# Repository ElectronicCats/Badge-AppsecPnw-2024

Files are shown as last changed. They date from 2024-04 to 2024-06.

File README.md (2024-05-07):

# Badge pnwCON 2024

## Getting started

1. Connect Badge via USB to your computer.
2. Open the serial port indicated for the badge on your computer through a program such as Arduino IDE, Putty or Screen at 115200 bauds.
3. The badge text should appear in the terminal.

## Tecnologia

- ESP32C6
- LEDs
- USB

## Gratitude
Do you want to say thank you? Tag these companies on social networks and show them your badge, thanks to them it is possible

- [WebSEC](https://www.websec.ca)
- [ElectronicCats](https://electroniccats.com/)

## License

Electronic Cats invests time and resources providing this open source design, please support Electronic Cats and open-source hardware by purchasing products from Electronic Cats!

Designed by Electronic Cats.

Hardware released under an CERN Open Hardware Licence v1.2. See the LICENSE_HARDWARE file for more information.

Electronic Cats is a registered trademark, please do not use if you sell these PCBs.

May 2024

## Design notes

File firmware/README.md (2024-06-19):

# AppsecPwn
Application in the firmware:
- Wifi
  - Deauth:
  - Broadcast: Send broadcast packets to the selected AP.
  - Rogue AP: Clone the selected AP.
  - Combine: Create a clone of the selected AP and send broadcast packets to the real AP.
  - Multi-AP: Create APs for all the scanned networks.
  - Captive portal:
    - Google: Request credentials from the user.
    - WIFI Pass: Steal the WiFi password by asking the user to enter their network password.
- BLE
  - Trackers: Scanner for Airtags and Tile devices.
  - Spam: Send ADV packets to connect devices to an Apple device.
  - Game: Game based on OWASP vulnerabilities.
- Zigbee
  - Sniffer: IEEE 802.15.4 Sniffer, requires a computer serial connection.
- Settings
  - Display: Change the logo screen. If the bonus logos are unlocked, this option allows you to change the logo.

## Game
When entering pairing mode, the game must have a Blue team player and a Red team player. The devices need to be close to each other to start the game. Once started, the Red team player selects the OWASP profile to use and then the attack. When the attack is sent, the Blue team player receives it and must select a mitigation measure. If the mitigation is successful, the Blue team wins the round and the Red team loses points. The game ends when either team loses all their points.

### Unlocks
To unlock the logos, the player must win 10 games using the 10 OWASP profiles. Every 3 profiles unlock a new level until the highest level is reached.
Levels:
Jedi:
Level 1: Padawan
Level 2: Knight
Level 3: Master
Level 4: Grand Master <- Highest Level
Sith:
Level 1: Lord
Level 2: Master
Level 3: Darth
Level 4: Dark Lord <- Highest level

It is not required to unlock the backgrounds in a specific order; the condition is to win games with different profiles. To unlock faster, it is convenient to win each game using different attacks. Each game saves which profile was used; if you win with those profiles, an internal flag is set which allows you to level up.

### Profile map

#### Part 1
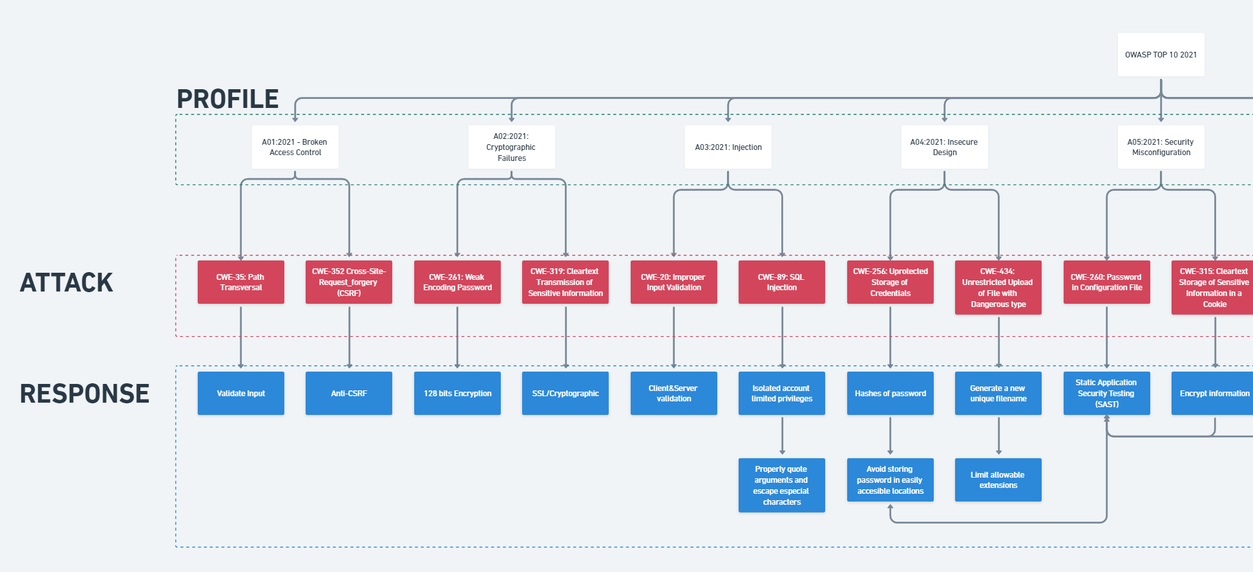
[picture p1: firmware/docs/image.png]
Part 1 - Profile map

#### Part 2
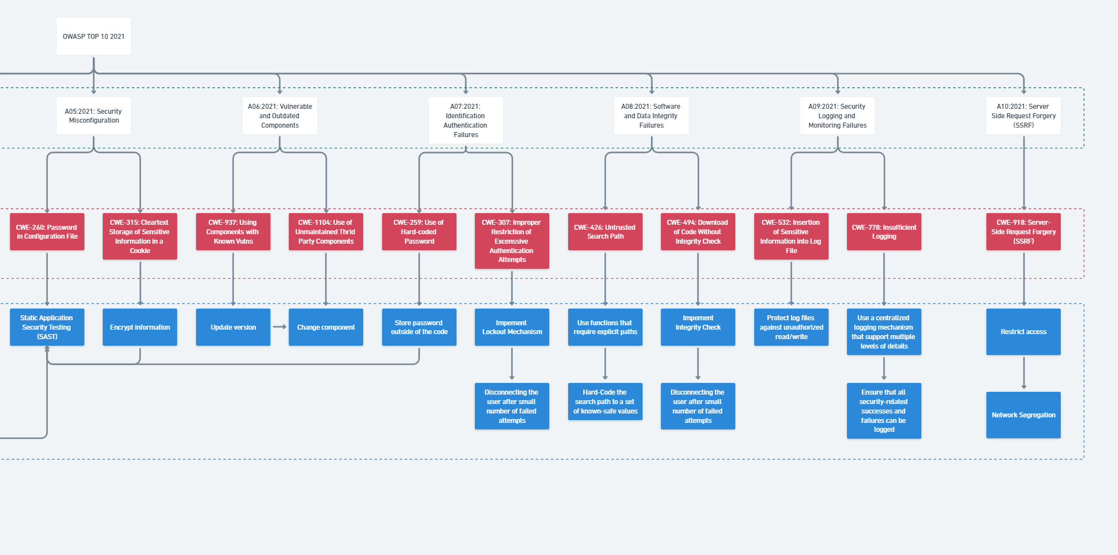
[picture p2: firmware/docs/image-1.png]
Part 2 - Profile map


### Logos
#### Sith Logo
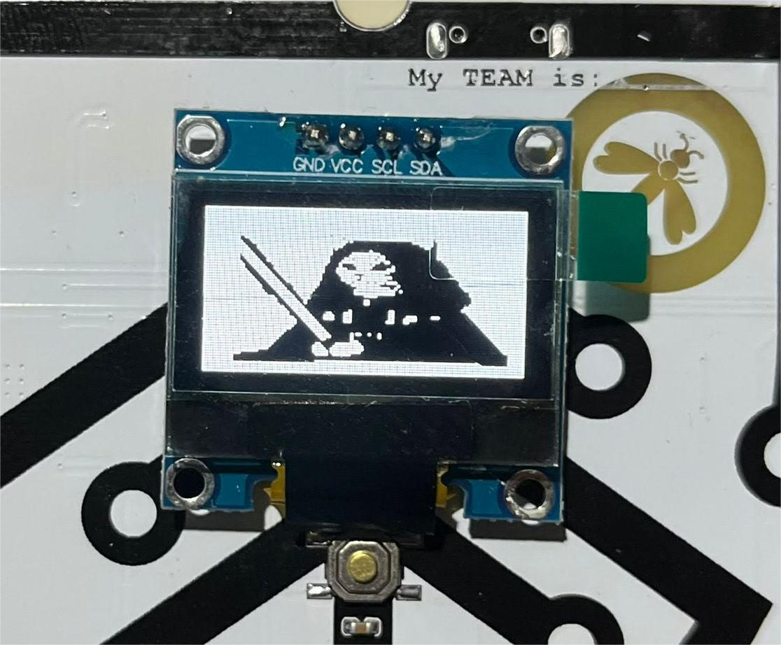
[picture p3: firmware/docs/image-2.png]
Sith logo

#### Jedi Logo
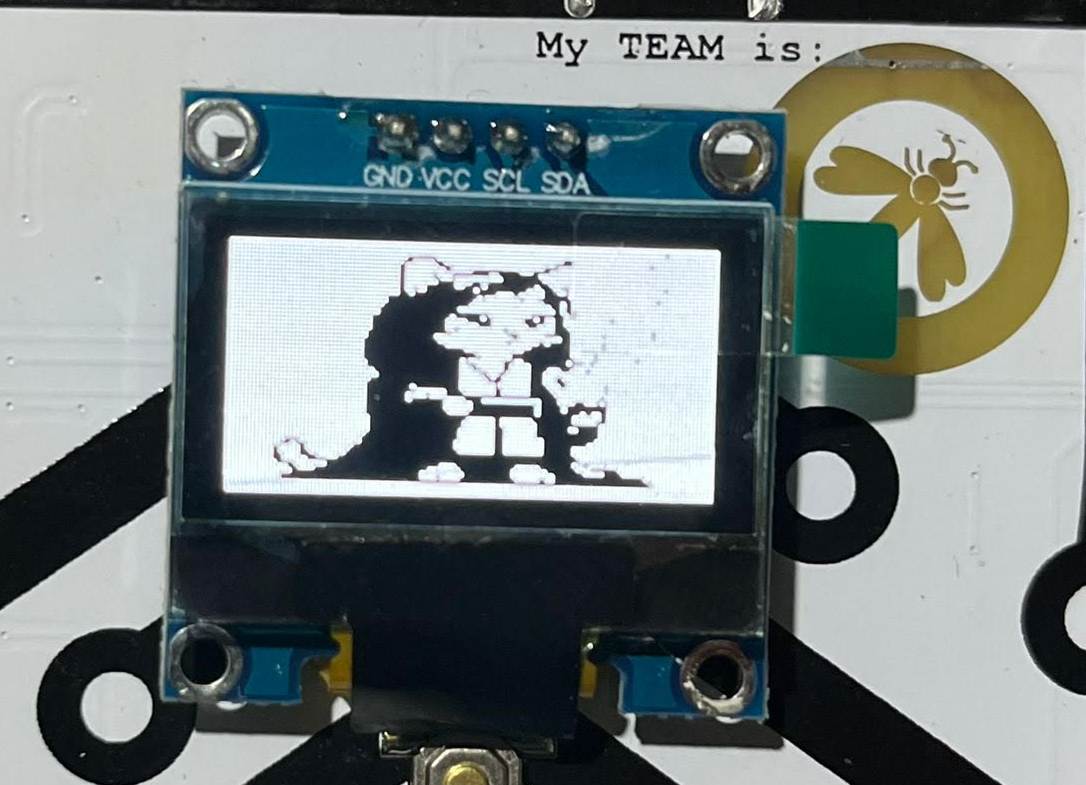
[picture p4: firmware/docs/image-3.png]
Jedi log


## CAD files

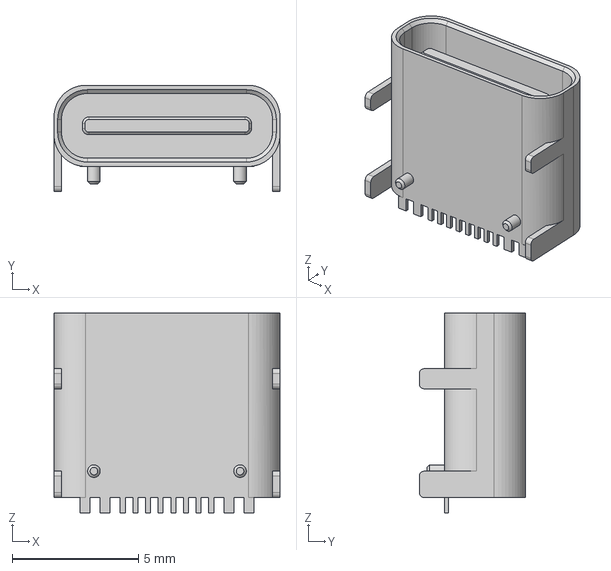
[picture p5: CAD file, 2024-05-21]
hardware/Footprints/3D/HRO TYPE-C-31-M-12.step
8.94 x 4.21 x 7.90 mm

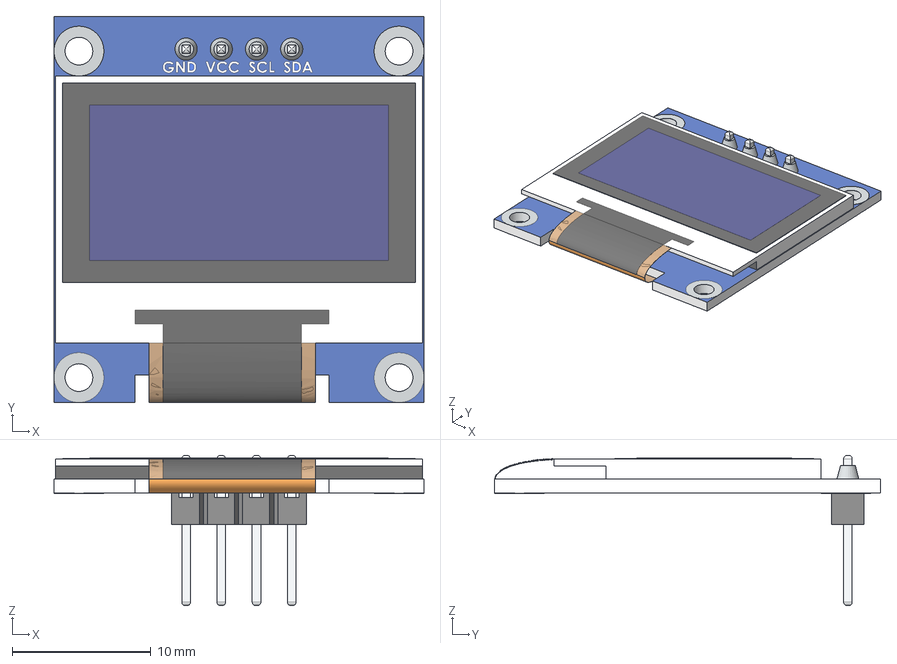
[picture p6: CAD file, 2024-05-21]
hardware/Footprints/3D/OLED-128x64-0.96.step
26.7 x 27.9 x 10.8 mm

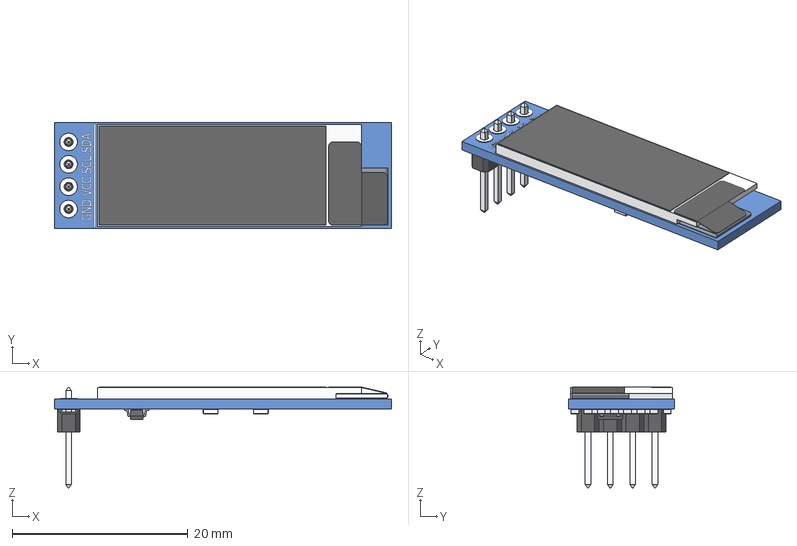
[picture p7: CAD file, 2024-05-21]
hardware/Footprints/3D/OLED_0.91_128x32.stp
38.3 x 12.1 x 11.5 mm
OLED_0.91_128x32
Pin Header 4 x 1 TH 2.54mm Pitch
RESC-0603 x 13
2SD0601A

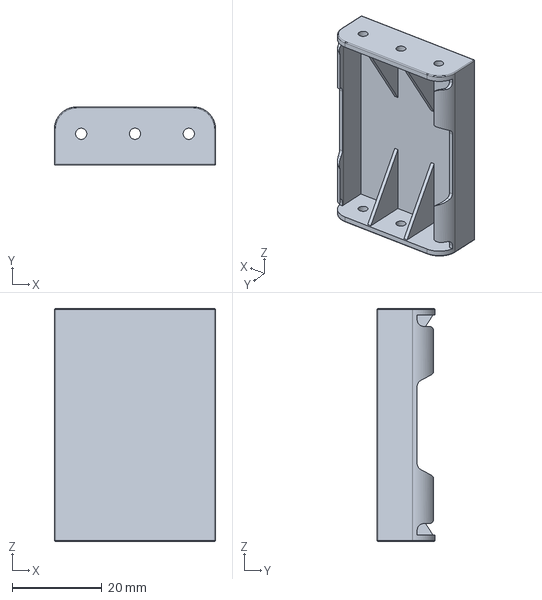
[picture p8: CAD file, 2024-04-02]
hardware/Footprints/3D/3x AAA battery holder.stp
36.0 x 13.0 x 52.0 mm

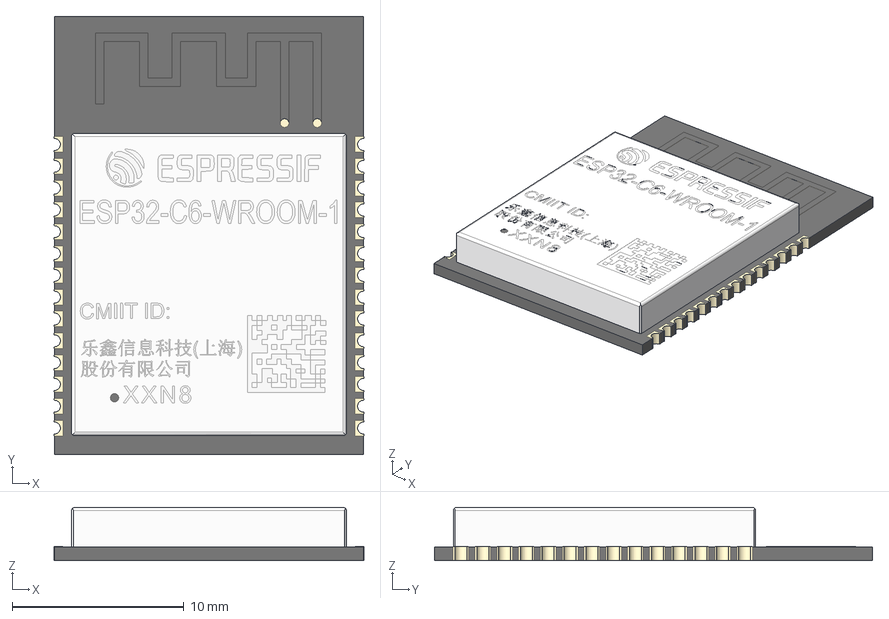
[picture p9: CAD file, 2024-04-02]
hardware/Footprints/3D/ESP32-C6-WROOM-1-N4.step
18.0 x 25.5 x 3.11 mm

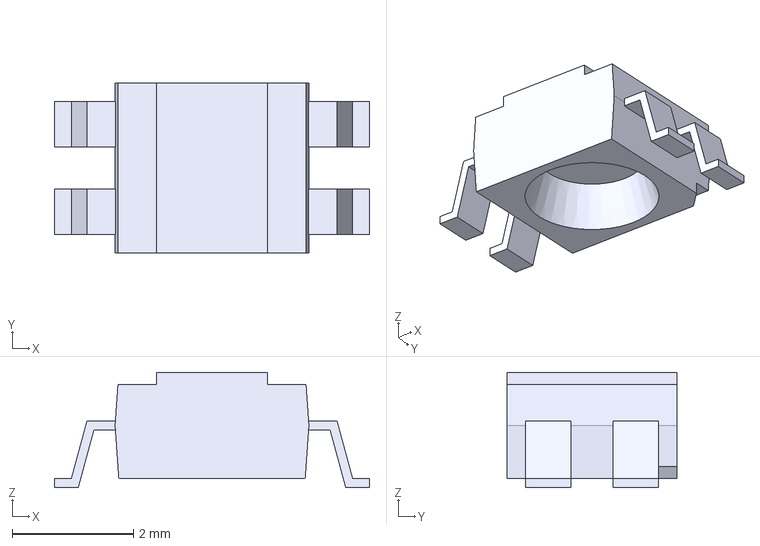
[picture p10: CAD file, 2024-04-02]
hardware/Footprints/3D/AAA3528RBGS_08-09.step
5.20 x 2.80 x 1.90 mm
root
AAA3528-09.STEP

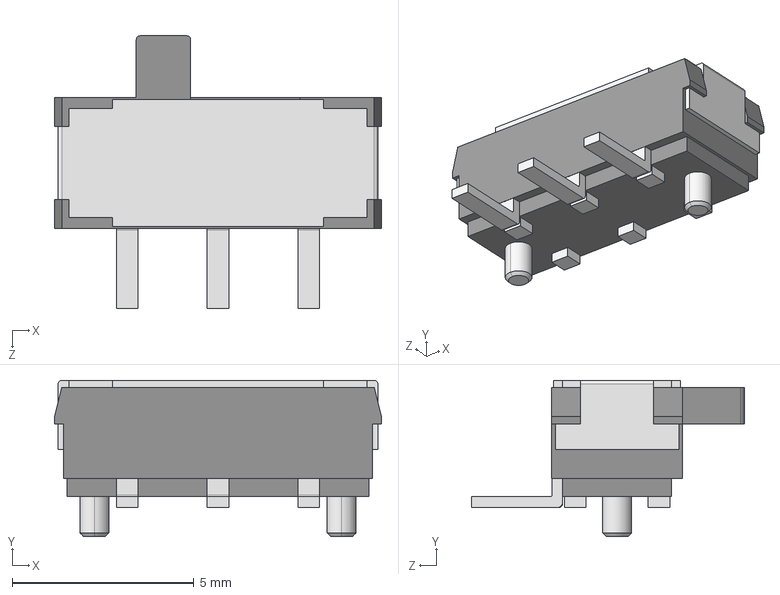
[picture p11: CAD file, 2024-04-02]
hardware/Footprints/3D/JS102011SAQN.STEP
9.00 x 4.30 x 7.50 mm

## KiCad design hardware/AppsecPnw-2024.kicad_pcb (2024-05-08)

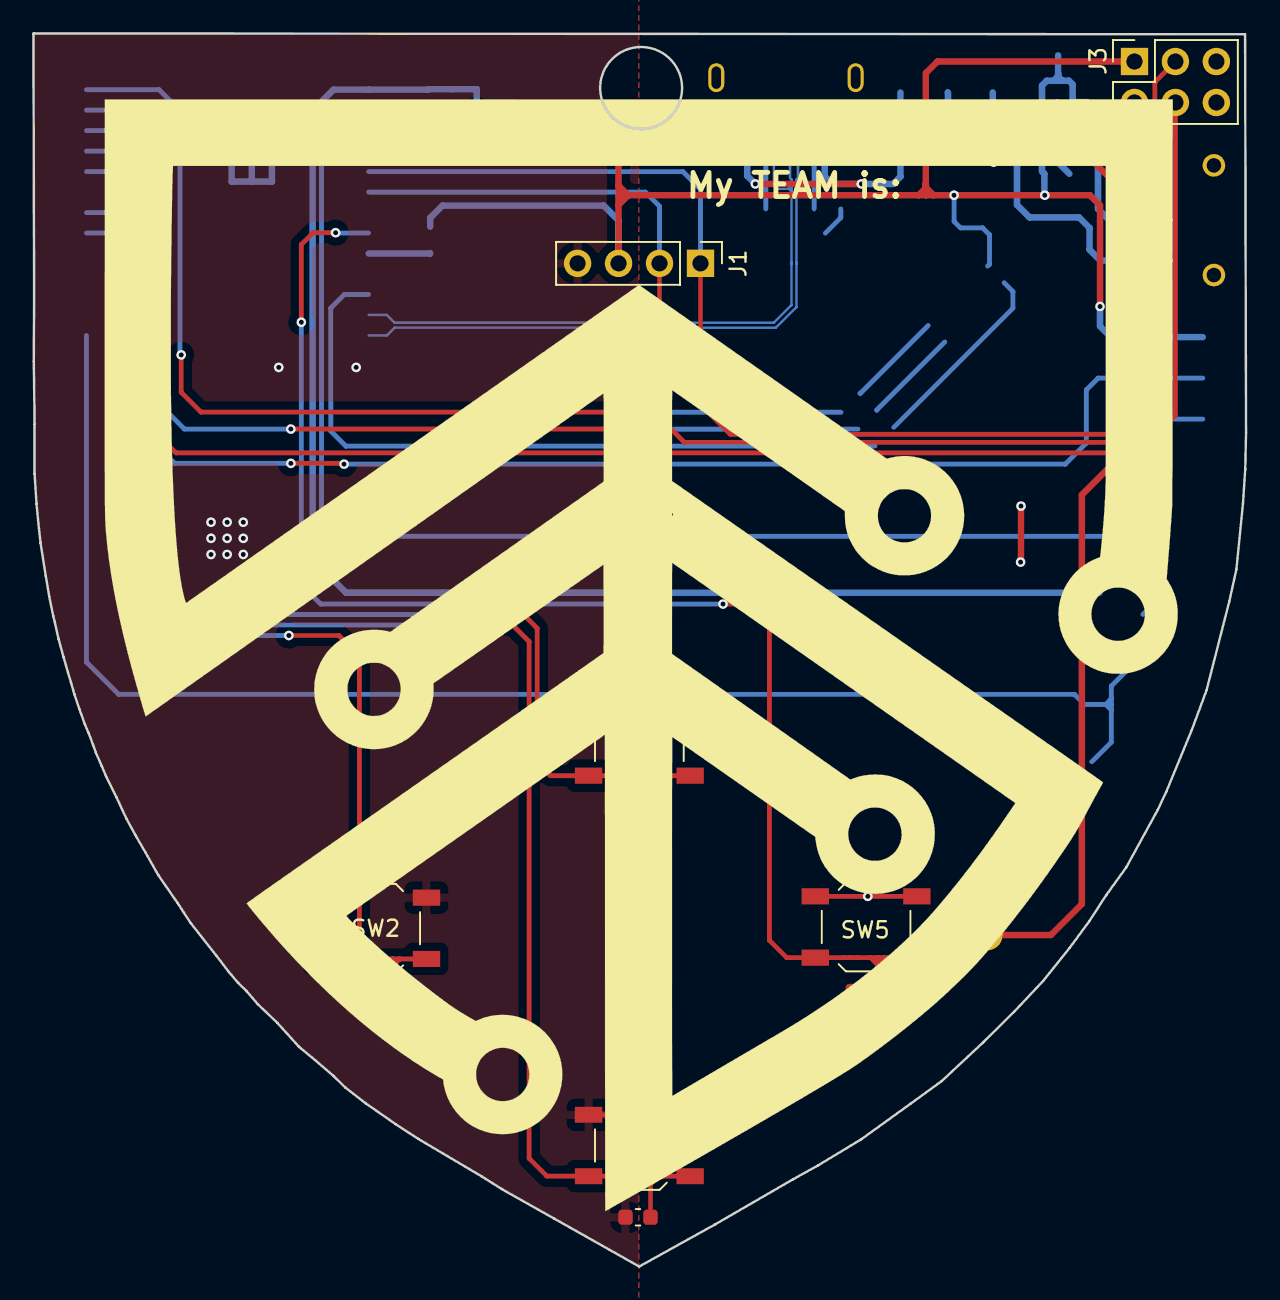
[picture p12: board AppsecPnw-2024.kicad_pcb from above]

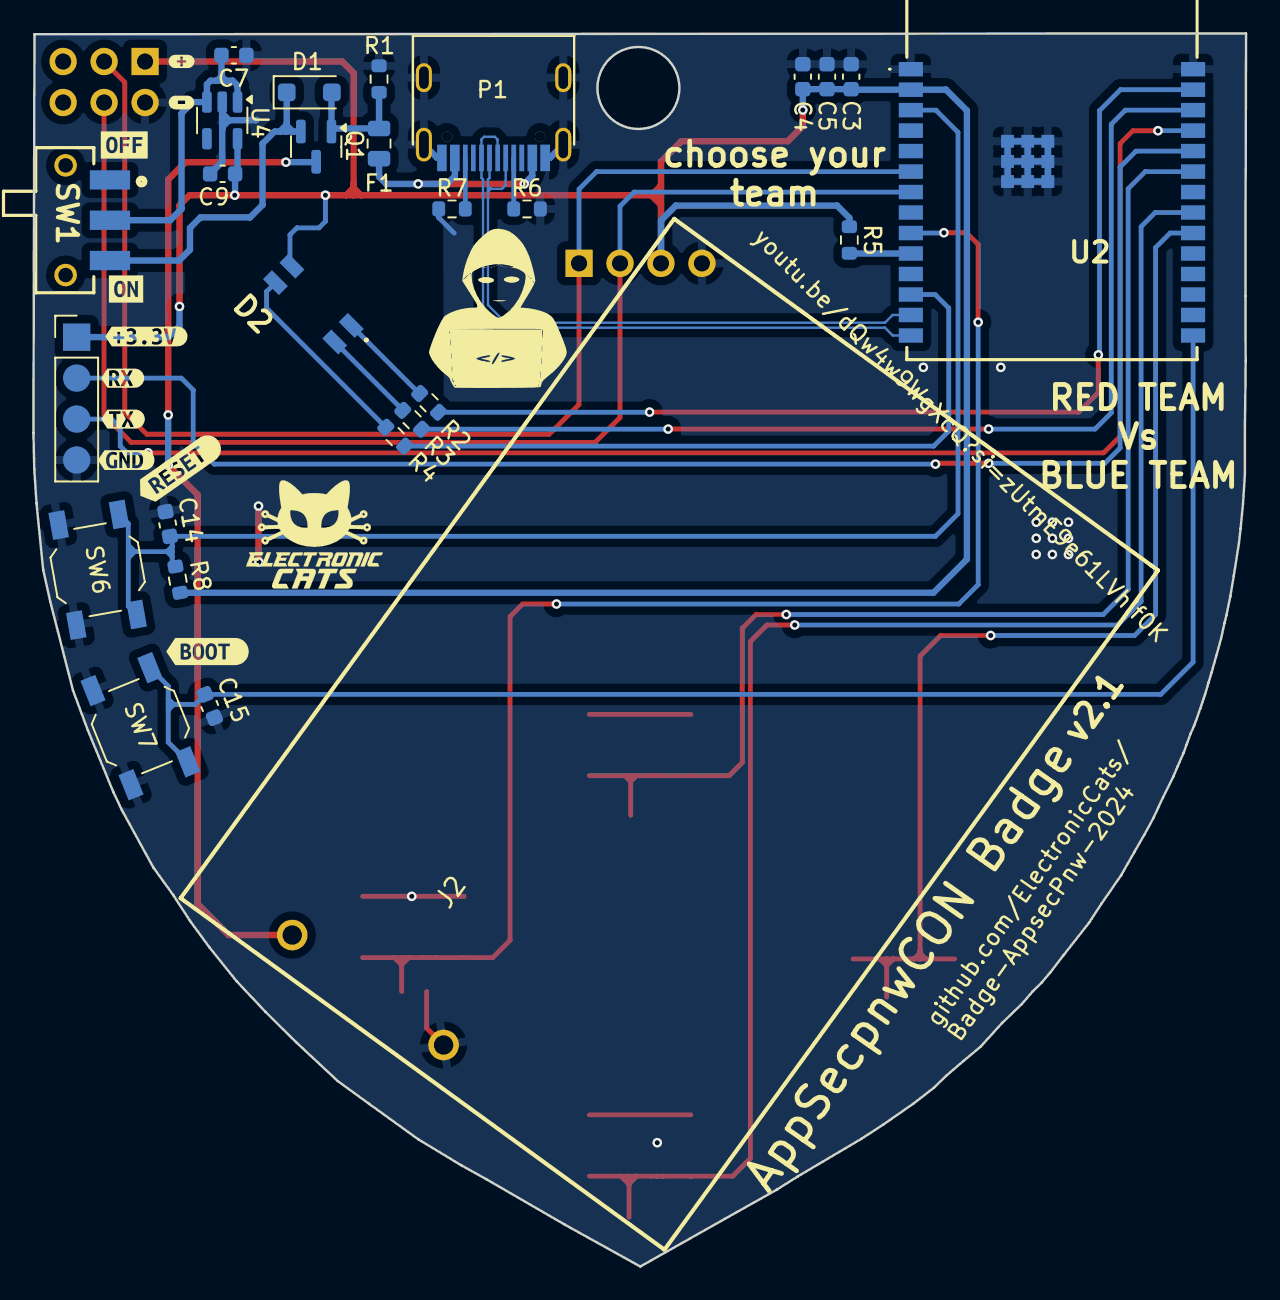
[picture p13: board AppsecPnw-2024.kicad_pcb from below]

Board: 2 copper layers, 75.2 x 76.5 mm, 48 parts (37 on the bottom side), 28 nets.

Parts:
C3: 1uF; C_0603_1608Metric
C4, C5, C7, C9: 10uF; C_0603_1608Metric
C10, C11, C12, C13, C14, C15: .1uF; C_0603_1608Metric
D1: MBR120; D_SOD-123F
D2: LED_RABG; AAA3528SURKCGKC09
F1: 1A; Fuse_0805_2012Metric
J1: OLED; Display OLED 128 x32
J2: Battery; BAT-TH_BH-AAA-A1AJ024
J3: Conn_02x03_Odd_Even; PinSocket_2x03_P2.54mm_Vertical
J5: UART; PinHeader_1x04_P2.54mm_Vertical
P1: USB_C_Plug_USB2.0; C393939
Q1: DMG3415U-7; SOT-23
R1: 100K; R_0603_1608Metric
R2, R3, R4: 330; R_0603_1608Metric
R5: 3.3K; R_0603_1608Metric
R6, R7: 5k1; R_0603_1608Metric
R8: 10K; R_0603_1608Metric
Ref**: Val**; Badge pnwcon
SW1: ON; JS102011SAQN
SW2: LEFT; SW_SPST_TL3342
SW3: DOWN; SW_SPST_TL3342
SW4: UP; SW_SPST_TL3342
SW5: RIGTH; SW_SPST_TL3342
SW6: RESET; SW_SPST_TL3342
SW7: BOOT; SW_SPST_TL3342
U2: ESP32-C6-WROOM-1-N4; ESP32C6WROOM1N4
U4: AP2112K-3.3; SOT-23-5
kibuzzard-660EECB7: G***; kibuzzard-660EECB7
kibuzzard-660EEDFA: G***; kibuzzard-660EEDFA
kibuzzard-663AC028: G***; kibuzzard-663AC028
kibuzzard-663AC038: G***; kibuzzard-663AC038
kibuzzard-663AC049: G***; kibuzzard-663AC049
kibuzzard-663AC054: G***; kibuzzard-663AC054
kibuzzard-6616FF4C: G***; kibuzzard-6616FF4C
kibuzzard-6616FF56: G***; kibuzzard-6616FF56
kibuzzard-6617003A: G***; kibuzzard-6617003A
kibuzzard-66170030: G***; kibuzzard-66170030

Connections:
+3V3: C3.1, C4.1, C5.1, C9.1, D2.2 (A), J1.3, J3.1, J5.1, R5.1, R8.2, U2.2 (3V3), U4.5 (VOUT)
+BATT: J2.2, Q1.3 (D)
/BACK: C10.2, SW2.2, U2.20 (IO22)
/BLUE: R4.1, U2.12 (IO11)
/BOOT: C15.2, SW7.2, U2.15 (IO9)
/D+: P1.A6 (D+), U2.14 (IO13)
/D-: P1.A7 (D-), U2.13 (IO12)
/DOWN: C11.2, SW3.2, U2.21 (IO23)
/EN: C14.2, R8.1, SW6.2, U2.3 (EN)
/GREEN: R3.1, U2.26 (IO3)
/IO8: R5.2, U2.10 (IO8)
/RED: R2.1, U2.27 (IO2)
/RX: J5.2, U2.24 (RXD0)
/SCL: J1.2, J3.4, U2.7 (IO7)
/SDA: J1.1, J3.3, U2.6 (IO6)
/SELECT: C13.2, SW5.2, U2.9 (IO1)
/TX: J5.3, U2.25 (TXD0)
/UP: C12.2, SW4.2, U2.23 (IO15)
GND: C3.2, C4.2, C5.2, C7.2, C9.2, C10.1, C11.1, C12.1, C13.1, C14.1, C15.1, J1.4, J2.1, J3.2, J5.4, P1.A1 (GND), P1.S1 (SHIELD), R1.2, R6.1, R7.1, SW2.1, SW3.1, SW4.1, SW5.1, SW6.1, SW7.1, U2.1 (GND_1), U2.28 (GND_2), U2.29 (GND_3), U2.30 (GND_4), U2.31 (GND_5), U2.32 (GND_6), U2.33 (GND_7), U2.34 (GND_8), U2.35 (GND_9), U2.36 (GND_10), U2.37 (GND_11), U4.2 (GND)
unnamed: D1.1 (K), Q1.2 (S), SW1.3 (A)
unnamed: D2.3 (BK), R4.2
unnamed: D2.4 (GK), R3.2
unnamed: D2.1 (RK), R2.2
unnamed: F1.1, P1.A4 (VBUS)
unnamed: P1.A5 (CC), R6.2
unnamed: P1.B5 (VCONN), R7.2
unnamed: C7.1, SW1.2 (B), U4.1 (VIN), U4.3 (EN)
VBUS: D1.2 (A), F1.2, Q1.1 (G), R1.1

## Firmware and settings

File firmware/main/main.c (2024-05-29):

/*
* Electronic Cats AppsecPwn CTF 2024

* This file is part of the Electronic Cats AppsecPwn CTF 2024 project.
*/
#include "esp_event.h"
#include "esp_log.h"
#include "modules/cross_keyboard_module.h"
#include "modules/game_screens_module.h"
#include "modules/menu_screens_modules.h"
#include "preferences.h"
#include "modules/led_events.h"

const char* TAG_MAIN = "MAIN";

void app_main(void) {
  // esp_log_set_level_master(ESP_LOG_INFO);
  ESP_ERROR_CHECK(esp_event_loop_create_default());
  esp_err_t err = preferences_begin();
  if (err != ESP_OK) {
    ESP_LOGE(TAG_MAIN, "Error initializing preferences: %s",
             esp_err_to_name(err));
  }
  // preferences_clear();
  module_keyboard_begin();
  screen_module_begin();
  int last_layer = preferences_get_int("MENUNUMBER", 99);
  if (last_layer == 99) {
    screen_module_set_main_menu();
    screen_module_display_badge_logo();
  } else {
    screen_module_set_screen(last_layer);
    screen_module_display_menu();
    preferences_put_int("MENUNUMBER", 99);
  }
}

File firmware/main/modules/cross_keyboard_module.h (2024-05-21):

#include "iot_button.h"
#ifndef CROSS_KEYBOARD_MODULE_H
  #define CROSS_KEYBOARD_MODULE_H

  #define TAG_CROSS_KEYBOARD_MODULE "KEYBOARD_MODULE"
  #define BOOT_BUTTON_PIN           CONFIG_BOOT_BUTTON
  #define LEFT_BUTTON_PIN           CONFIG_GPIO_LEFT_BUTTON
  #define RIGHT_BUTTON_PIN          CONFIG_GPIO_RIGHT_BUTTON
  #define UP_BUTTON_PIN             CONFIG_GPIO_UP_BUTTON
  #define DOWN_BUTTON_PIN           CONFIG_GPIO_DOWN_BUTTON

  #define BOOT_BUTTON_MASK  0b0000 << 4
  #define LEFT_BUTTON_MASK  0b0001 << 4
  #define RIGHT_BUTTON_MASK 0b0010 << 4
  #define UP_BUTTON_MASK    0b0011 << 4
  #define DOWN_BUTTON_MASK  0b0100 << 4

  #define BUTTON_ACTIVE_LEVEL 0
/**
 * @brief Events for the available keyboard buttons events
 *
 */
static const char* button_events_name[] = {
    "BUTTON_PRESS_DOWN",      "BUTTON_PRESS_UP",
    "BUTTON_PRESS_REPEAT",    "BUTTON_PRESS_REPEAT_DONE",
    "BUTTON_SINGLE_CLICK",    "BUTTON_DOUBLE_CLICK",
    "BUTTON_MULTIPLE_CLICK",  "BUTTON_LONG_PRESS_START",
    "BUTTON_LONG_PRESS_HOLD", "BUTTON_LONG_PRESS_UP",
};

/**
 * @brief Layout of the available keyboard buttons names
 *
 */
static const char* button_names[] = {
    "BOOT", "LEFT", "RIGHT", "UP", "DOWN",
};

/**
 * @brief Enum of the available keyboard buttons
 *
 */
typedef enum {
  BUTTON_BOOT = 0,
  BUTTON_LEFT,
  BUTTON_RIGHT,
  BUTTON_UP,
  BUTTON_DOWN,
} keyboard_buttons_layout_t;

/**
 * @brief Struct to hold the button state
 *
 */
typedef struct {
  uint8_t button_pressed;
  uint8_t button_event;
} button_event_state_t;

/**
 * @brief Initialize the keyboard button
 *
 * @param uint32_t button_pin Button pin
 * @param uint8_t mask Mask
 * @param void handler function pointer for the button event callback
 *
 * @return void
 */
void keyboard_driver_button_init(uint32_t button_pin, uint8_t mask);

/**
 * @brief Register the event callback for the keyboard button
 *
 * @param button_handle_t button_handle
 * @param uint8_t mask
 *
 * @return void
 */
void keyboard_driver_button_register_event_cb(button_handle_t button_handle,
                                              uint8_t mask);

/**
 * @brief Keyboard button event callback
 *
 * @param void* arg
 * @param void* data
 *
 * @return void
 */
void module_keyboard_button_event_cb(void* arg, void* data);

/**
 * @brief Initialize the keyboard module
 *
 * @return void
 */
void module_keyboard_begin();

#endif  // CROSS_KEYBOARD_MODULE_H

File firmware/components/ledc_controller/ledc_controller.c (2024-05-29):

#include "ledc_controller.h"
#include "driver/gpio.h"
#include "driver/ledc.h"
#include "esp_check.h"
#include "esp_err.h"
#include "esp_log.h"
#include "esp_timer.h"
#include "freertos/FreeRTOS.h"
#include "freertos/semphr.h"
#include "freertos/task.h"
#include "string.h"

static const char* TAG = "LED_CONTROLLER";

#define LEDC_TIMER     LEDC_TIMER_0
#define LEDC_MODE      LEDC_LOW_SPEED_MODE
#define LEDC_DUTY_RES  LEDC_TIMER_8_BIT  // Set duty resolution to 8 bits
#define LEDC_FREQUENCY (4000)  // Frequency in Hertz. Set frequency at 4 kHz

// LED Effect State Enum
// This enum represents the different states of the LED effects.
typedef enum {
  LED_EFFECT_NONE,    // No effect active
  LED_EFFECT_BREATH,  // Breath effect active
  LED_EFFECT_BLINK    // Blink effect active
} led_effect_state_t;

// LED Breath Structure
// This structure represents the breath effect data for a LED.
typedef struct {
  led_t* led;                // Pointer to the LED
  esp_timer_handle_t timer;  // Timer handle for the breath effect
  float brightness;          // Current brightness of the LED
  float step;                // Step size for increasing/decreasing brightness
} led_breath_t;

// LED Blink Structure
// This structure represents the blink effect data for a LED.
typedef struct {
  led_t* led;                // Pointer to the LED
  uint8_t duty;              // Led intensity for blink effect
  esp_timer_handle_t timer;  // Timer handle for the blink effect
  uint32_t time_on;          // Duration of the LED ON state during each pulse
  uint32_t time_off;         // Duration of the LED OFF state during each pulse
  uint32_t time_out;         // Timeout duration for the blink effect
  uint8_t pulse_count;       // Number of pulses for the blink effect
} led_blink_t;

// LED Effects Structure
// This structure represents the effects data for an RGB LED.
typedef struct {
  led_t* led;                       // Pointer to the RGB LED
  led_effect_state_t effect_state;  // Current effect state
  led_breath_t breath_effect;       // Breath effect data
  led_blink_t blink_effect;         // Blink effect data
  // Add any additional fields you need for other effects
} led_effects_t;

// Maximum number of LEDs for breath effect
#define MAX_LEDS 3  // max 8 ledc_channels

// Array to hold the breath and blink effect data for multiple LEDs
static led_effects_t led_effects[MAX_LEDS];

// Number of breath and blink effect LEDs currently active
static int num_led_effects = 0;

static int get_led_index(led_t* led) {
  // Check if the blink effect is already active for the specified LED
  for (int i = 0; i < num_led_effects; i++) {
    if (led_effects[i].led == led) {
      return i;
    }
  }
  return -1;
}

/**
 * @brief Sets up a LEDC channel to control a specific LED.
 *
 * @description This function sets up one of the ESP32's LEDC (LED Controller)
 * channels to control a specific LED. It first sets up a LEDC timer with a
 * predefined configuration (8-bit duty resolution, 4000 Hz frequency,
 * high-speed mode, timer number 0). It then configures the LEDC channel to use
 * the provided GPIO and the LEDC timer. The LED is initially off (duty = 0).
 * The function returns ESP_OK if the setup was successful. If there was an
 * error, it returns an appropriate ESP_ERR code.
 *
 * @param led_gpio The GPIO number of the LED to control.
 * @param led_channel The LEDC channel to use for the LED.
 * @return esp_err_t ESP_OK if successful, or an error code if not.
 */
static esp_err_t setup_ledc(int led_gpio, ledc_channel_t led_channel) {
  // Set LEDC timer configuration
  ledc_timer_config_t ledc_timer = {
      .speed_mode = LEDC_MODE,
      .duty_resolution = LEDC_DUTY_RES,
      .timer_num = LEDC_TIMER,
      .freq_hz = LEDC_FREQUENCY,  // Set output frequency at 4 kHz
      .clk_cfg = LEDC_AUTO_CLK};

  // Set the configuration
  esp_err_t err = ledc_timer_config(&ledc_timer);
  if (err != ESP_OK)
    return err;

  // Prepare individual configuration for each LED
  ledc_channel_config_t ledc_channel_cfg = {.speed_mode = LEDC_MODE,
                                            .channel = led_channel,
                                            .timer_sel = LEDC_TIMER,
                                            .intr_type = LEDC_INTR_DISABLE,
                                            .gpio_num = led_gpio,
                                            .duty = 0,  // Set duty to 0%
                                            .hpoint = 0};

  ledc_fade_func_install(NULL);

  // Set the configuration
  return ledc_channel_config(&ledc_channel_cfg);
}

/**
 * @brief Set the duty cycle of a PWM LED
 *
 * @description This function sets the duty of a PWM LED. The
 * duty is specified as a 8-bit PWM duty value.If an
 * error occurs while setting the duty cycle, an appropriate ESP_ERR code is
 * returned.
 *
 * @param led A pointer to the led_t structure that contains the
 * configuration of the LED.
 * @param duty The 8-bit duty cycle value.
 * @return esp_err_t ESP_OK if successful, or an error code if not.
 */
static esp_err_t set_duty(led_t* led, uint8_t duty) {
  if (!led) {
    return ESP_ERR_INVALID_ARG;
  }
  ESP_RETURN_ON_ERROR(
      ledc_set_duty_and_update(LEDC_LOW_SPEED_MODE, led->channel, duty, 0), TAG,
      "Failed to set red duty");

  return ESP_OK;
}

esp_err_t led_controller_led_init(led_t* led_cfg) {
  esp_err_t ret = ESP_OK;

  if (!led_cfg) {
    return ESP_ERR_INVALID_ARG;
  }

  led_t led = *led_cfg;

  // Check that the pin is valid for output
  ESP_GOTO_ON_FALSE(GPIO_IS_VALID_OUTPUT_GPIO(led.pin), ESP_ERR_INVALID_ARG,
                    err, TAG, "Invalid red_pin");

  // Configure the GPIO pin for output
  ESP_ERROR_CHECK(gpio_set_direction(led.pin, GPIO_MODE_OUTPUT));

  ESP_ERROR_CHECK(gpio_set_level(led.pin, 1));

  ESP_RETURN_ON_ERROR(setup_ledc(led.pin, led.channel), TAG,
                      "Failed to setup LED");

  for (int i = 0; i < num_led_effects; i++) {
    if (led_effects[i].led == led_cfg) {
      ESP_LOGE(TAG, "LED already present in led_effects array");
      return ESP_ERR_INVALID_STATE;
    }
  }

  // LED not found in the led_effects array, create a new LED effect
  if (num_led_effects >= MAX_LEDS) {
    ESP_LOGE(TAG, "Maximum number of LEDs reached, unable to add LED effect.");
    return ESP_FAIL;  // Maximum number of LEDs reached, unable to add LED
                      // effect
  }

  led_effects[num_led_effects].led = led_cfg;
  num_led_effects++;

  return ESP_OK;

  // Error handling block
err:
  ESP_LOGE(TAG, "Invalid argument: %s", esp_err_to_name(ret));
  return ret;
}

led_t led_controller_led_new(gpio_num_t pin, ledc_channel_t ch) {
  led_t led;
  led.pin = pin;
  led.channel = ch;
  return led;
}
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

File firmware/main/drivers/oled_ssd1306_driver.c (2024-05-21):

#include "drivers/oled_ssd1306_driver.h"

#include <stdlib.h>
#include <string.h>
#include "esp_log.h"
#include "ssd1306.h"

SSD1306_t p_driver_screen;

void oled_driver_init() {
#if CONFIG_I2C_INTERFACE
  ESP_LOGI(TAG_OLED_DRIVER, "INTERFACE: I2C");
  ESP_LOGI(TAG_OLED_DRIVER, "CONFIG_SDA_GPIO=%d", CONFIG_SDA_GPIO);
  ESP_LOGI(TAG_OLED_DRIVER, "CONFIG_SCL_GPIO=%d", CONFIG_SCL_GPIO);
  ESP_LOGI(TAG_OLED_DRIVER, "CONFIG_RESET_GPIO=%d", CONFIG_RESET_GPIO);
  i2c_master_init(&p_driver_screen, CONFIG_SDA_GPIO, CONFIG_SCL_GPIO,
                  CONFIG_RESET_GPIO);
#endif  // CONFIG_I2C_INTERFACE
#if CONFIG_SPI_INTERFACE
  ESP_LOGI(TAG_OLED_DRIVER, "INTERFACE: SPI");
  ESP_LOGI(TAG_OLED_DRIVER, "CONFIG_MOSI_GPIO=%d", CONFIG_MOSI_GPIO);
  ESP_LOGI(TAG_OLED_DRIVER, "CONFIG_SCLK_GPIO=%d", CONFIG_SCLK_GPIO);
  ESP_LOGI(TAG_OLED_DRIVER, "CONFIG_CS_GPIO=%d", CONFIG_CS_GPIO);
  ESP_LOGI(TAG_OLED_DRIVER, "CONFIG_DC_GPIO=%d", CONFIG_DC_GPIO);
  ESP_LOGI(TAG_OLED_DRIVER, "CONFIG_RESET_GPIO=%d", CONFIG_RESET_GPIO);
  spi_master_init(&p_driver_screen, CONFIG_MOSI_GPIO, CONFIG_SCLK_GPIO,
                  CONFIG_CS_GPIO, CONFIG_DC_GPIO, CONFIG_RESET_GPIO);
#endif  // CONFIG_SPI_INTERFACE

#if CONFIG_FLIP
  p_driver_screen->flip = true;
#endif  // CONFIG_FLIP

#if CONFIG_SSD1306_128x64
  ESP_LOGI(TAG_OLED_DRIVER, "PANEL: 128x64");
  ssd1306_init(&p_driver_screen, 128, 64);
#endif  // CONFIG_SSD1306_128x64
#if CONFIG_SSD1306_128x32
  ESP_LOGI(TAG_OLED_DRIVER, "PANEL: 128x32");
  ssd1306_init(&p_driver_screen, 128, 32);
#endif  // CONFIG_SSD1306_128x32
}

void oled_driver_clear(bool invert) {
  ssd1306_clear_screen(&p_driver_screen, invert);
}

void oled_driver_display_text(int page, char* text, bool invert) {
  ssd1306_display_text(&p_driver_screen, page, text, strlen(text), invert);
}

void oled_driver_display_text_large(int page, char* text, bool invert) {
  ssd1306_display_text_x3(&p_driver_screen, page, text, strlen(text), invert);
}

void oled_driver_display_bitmap(int x_pos,
                                int y_pos,
                                uint8_t* bitmap,
                                int width,
                                int height,
                                bool invert) {
  ssd1306_bitmaps(&p_driver_screen, x_pos, y_pos, bitmap, width, height,
                  invert);
}

void oled_driver_display_fadeout(void) {
  ssd1306_fadeout(&p_driver_screen);
}

void oled_driver_display_text_scroll_left(int page, char* text, bool invert) {
  oled_driver_display_text(page, text, invert);
  ssd1306_hardware_scroll(&p_driver_screen, SCROLL_LEFT);
  vTaskDelay(2000 / portTICK_PERIOD_MS);
  ssd1306_hardware_scroll(&p_driver_screen, SCROLL_STOP);
}

void oled_driver_display_text_scroll_right(int page, char* text, bool invert) {
  oled_driver_display_text(page, text, invert);
  ssd1306_hardware_scroll(&p_driver_screen, SCROLL_RIGHT);
  vTaskDelay(2000 / portTICK_PERIOD_MS);
  ssd1306_hardware_scroll(&p_driver_screen, SCROLL_STOP);
}

void oled_driver_software_scroll(int page_start, int page_end) {
  if (page_end > 0) {
    ssd1306_software_scroll(&p_driver_screen, page_start, page_end);
  } else {
    ssd1306_software_scroll(&p_driver_screen, page_start,
                            (p_driver_screen._pages - 1));
  }
}

void oled_driver_display_scroll_text(char* text, bool invert) {
  ssd1306_scroll_text(&p_driver_screen, text, strlen(text), invert);
}

void oled_driver_clear_line(int page, bool invert) {
  ssd1306_clear_line(&p_driver_screen, page, invert);
}

void oled_driver_display_text_center(int page, char* text, bool invert) {
  int text_length = strlen(text);
  int max_char_len = MAX_LINE_CHAR;
  if (text_length > max_char_len) {
    ESP_LOGE(TAG_OLED_DRIVER, "Text too long to center");
    oled_driver_display_text(page, text, invert);
    return;
  }

  // We need to know if the text is odd or even
  int text_center = (max_char_len - text_length) / 2;
  char text_centered[MAX_LINE_CHAR] = "";
  for (int i = 0; i < text_center; i++) {
    strcat(text_centered, " ");
  }
  strcat(text_centered, text);
  int text_centered_len = strlen(text_centered);
  for (int i = text_centered_len; i < max_char_len; i++) {
    strcat(text_centered, " ");
  }
  oled_driver_display_text(page, text_centered, invert);
}

void oled_driver_display_text_splited(char* p_text,
                                      int* p_started_page,
                                      int invert) {
  if (strlen(p_text) > MAX_LINE_CHAR) {
    char temp[50];
    strncpy(temp, p_text, 50);

    char* token = strtok(temp, " ");
    char current_line[MAX_LINE_CHAR] = "";
    while (token != NULL) {
      if (strlen(current_line) + strlen(token) + 1 <= MAX_LINE_CHAR) {
        if (strlen(current_line) > 0) {
          strcat(current_line, " ");
        }
        strcat(current_line, token);
      } else {
        oled_driver_display_text(*p_started_page, current_line, invert);
        (*p_started_page)++;
        strcpy(current_line, token);
      }
      token = strtok(NULL, " ");
    }
    if (strlen(current_line) > 0) {
      oled_driver_display_text(*p_started_page, current_line, invert);
      (*p_started_page)++;
    }
  } else {
    oled_driver_display_text(*p_started_page, p_text, invert);
    (*p_started_page)++;
  }
}

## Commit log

2024-03-27 feat(hw): init schematic
    [AppsecPnw-2024.kicad_pcb, AppsecPnw-2024.kicad_sch, AppsecPnw-2024.sch]
2024-03-28 feat(Hw) Init PCB
    [AppsecPnw-2024.kicad_pcb, AppsecPnw-2024.kicad_sch]
2024-04-02 feat(Hw) Update schematic and floorplan
    [3x AAA battery holder.stp, AAA3528RBGS_08-09.step, AppsecPnw-2024.kicad_pcb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]
2024-04-03 feat(Hw) Update schematic
    [AppsecPnw-2024.kicad_pcb, AppsecPnw-2024.kicad_sch, OLED-128x64-0.96.step]
2024-04-04 feat(main) : Engine for Red team
    - OLED Driver ssd1306
    - Keyboard handle
    - BLE pairing
    - OWASP Profiles
    - Game Engine profile selection
2024-04-04 feat(Hw): Update schematic and init route
    [AppsecPnw-2024.kicad_pcb, AppsecPnw-2024.kicad_sch]
2024-04-04 feat(hw):add logos
    [AppsecPnw-2024.kicad_pcb]
2024-04-04 feat(Hw): Update labels
    [AppsecPnw-2024.kicad_pcb]
2024-04-07 feat(engine): BLUE - RED Interaction
    - Interaction between Blue and Red device
    - Show screens for battle init
2024-04-10 feat(hw): lables rst and boot
    [AppsecPnw-2024.kicad_pcb]
2024-04-10 feat(hw): add labels on/off
    [AppsecPnw-2024.kicad_pcb]
2024-04-10 feat(Hw): Update BOM
    [AppsecPnw-2024.kicad_pcb, AppsecPnw-2024.kicad_sch]
2024-04-11 feat(hw): add tickness
    [AppsecPnw-2024.kicad_pcb]
2024-04-11 fix(Hw): Change F1
    [AppsecPnw-2024.kicad_sch]
2024-04-11 fix(Hw): fix dimensions layers and delete duplicated PCB thickness note
    [AppsecPnw-2024.kicad_pcb]
2024-04-13 feat: Engine communication
    - BLE Communication and first game steps
    [AppsecPnw-2024.kicad_pcb, AppsecPnw-2024.kicad_sch, AppsecPnw-2024.sch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]
2024-04-19 feat: Fix screen
    - Add ADV information
    - Correct some issues
    - Refactor scanner code
    [game_engine_module.h, main.c]
2024-04-20 feat: Fix clean code
    - Refactor some function
    - Clear comments
    [partitions.csv]
2024-04-21 feat: Implement Wifi Scanner
    - Wifi scanner for the attack
    - Screen animation
    [AppsecPnw-2024.kicad_pcb]
2024-04-22 feat: Implement Broadcast Packets
    - Send deauth frames
2024-04-22 feat: Implement combined attacks
    - Bugs correction
    - Test functionality
    - Clean and document code
    - Create attack screen
    - Create Wifi as component
    [main.c]
2024-04-30 feat: Implement BT Spam
    - Send bt packets
    - List of devices to spam
    - Some fixes in the Wifi and trackers
2024-04-30 feat: Fix bugs
    - Fix BLE game bugs
    - Fix menu scrolling items
    [game_engine_module.h]
2024-05-01 feat: Refactor
    - Correct bugs
    - Led status
    [led_events.c]
2024-05-01 feat: Implement Led lib
2024-05-02 feat: Fix bugs
    - BLE client pair by filter board name and RSSI
    - LED corrections
    - Engine fix bugs
    [led_events.c]
2024-05-07 feat: Implement random options
    - Fix bugs
    [game_engine_module.h, main.c]
2024-05-07 fix(Hw): Change PCB and pull up resistor for boot added
    [AppsecPnw-2024.kicad_pcb, AppsecPnw-2024.kicad_sch]
2024-05-08 feat(): add labels
    [AppsecPnw-2024.kicad_pcb]
2024-05-08 feat: Implement device screens
    Screens:
    - Licence
    - Version
    - Credits
    - Legal
    Zigbee change channel with Up and Down button
2024-05-20 feat: Merge conflicts
    - Change merge conflicts
    [AppsecPnw-2024.kicad_pcb]
2024-05-28 feat: Fix modules
    - Add long press exit in apps modules
    - Game dual badge
    - Game pairing exit
    [game_engine_module.h, led_events.c, main.c]
2024-05-29 feat: Fix bug
    - Change leds library
    - Solve I2C problem with wifi
    [led_events.c, ledc_controller.c, main.c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]
